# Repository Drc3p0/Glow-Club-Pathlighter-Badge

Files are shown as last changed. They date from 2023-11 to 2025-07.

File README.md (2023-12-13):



<br />
<div align="center">
  <a href="https://github.com/Drc3p0/Glow-Club-Pathlighter-Badge">
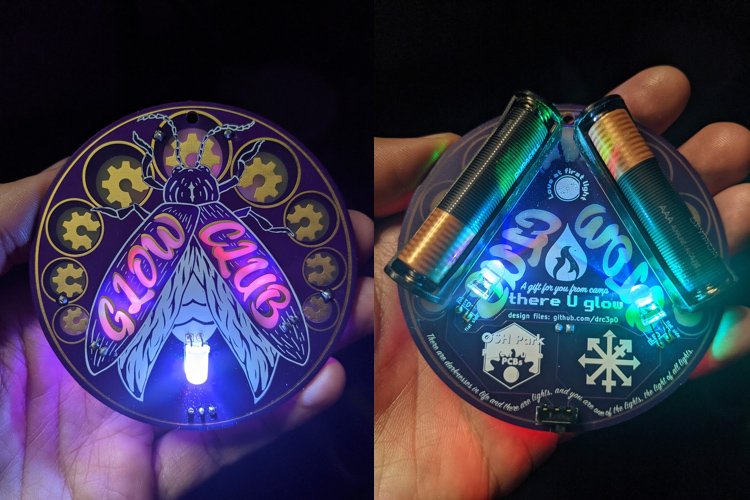
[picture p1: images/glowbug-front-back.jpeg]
glowclub pcb front and back
    
      </a>
 <a href="https://github.com/Drc3p0/Glow-Club-Pathlighter-Badge">
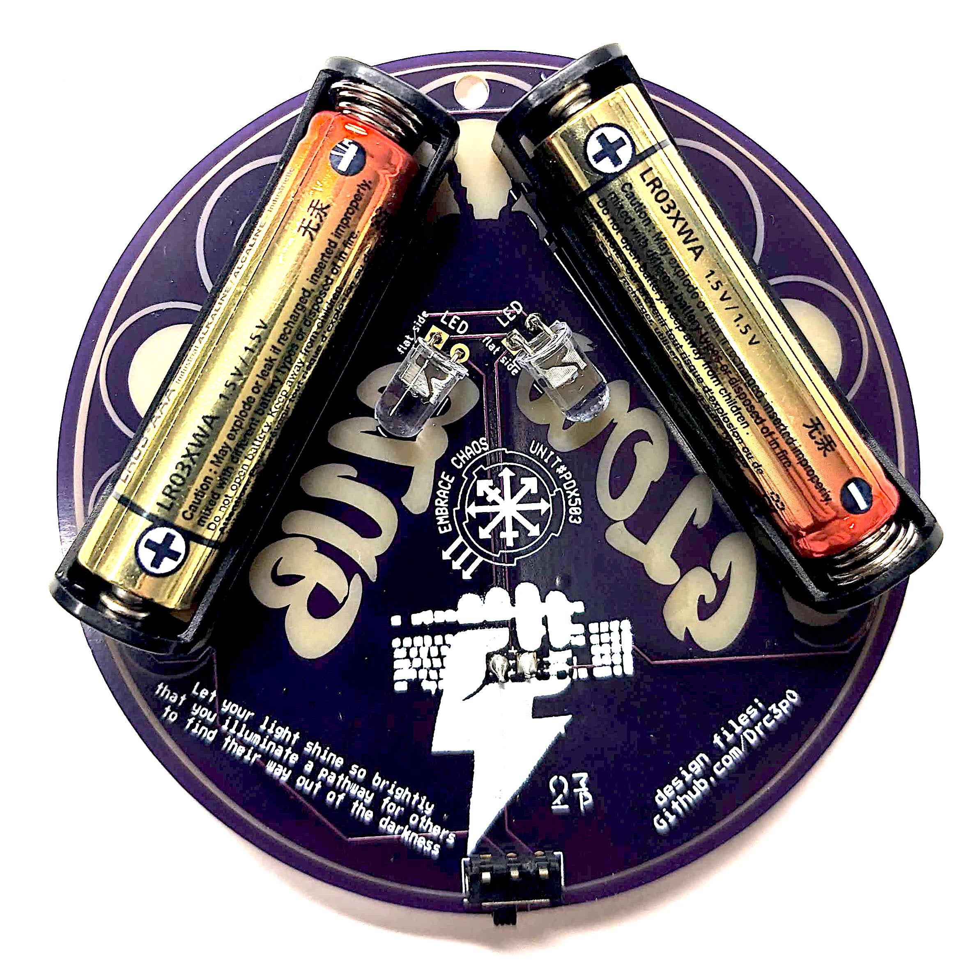
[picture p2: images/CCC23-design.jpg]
    
      </a>

<h3 align="center">Glow Club Pathlighter Badge</h3>

  <p align="center">
    wearable PCB art for the community
  
  </p>
</div>

<!-- ABOUT THE PROJECT -->
## About The Project
This PCB was created as a workshop aid to teach people about LEDs and soldering, and as a way to demistify the process of importing custom art layers into Kicad.  The PCB is intended to be worn on a lanyard, as a way to keep us all glowing safely at night. It was debuted at SOAK '22 for the There U Glow electronics education camp, used for a soldering workshop for ToorCamp 2022 participants, and at Chaos Communication Camp '23. 

signal-2022-07-20-17-38-53-745-3
  
### Created With

* [Procreate](https://procreate.art/)
* [Affinity Designer](https://affinity.serif.com/)
* [Kicad 6.0](https://kicad.org/)
* [OshPark](https://oshpark.com/)

The designs are free to be modified however you'd like.  

<div align="center">
  <a href="https://github.com/Drc3p0/Glow-Club-Pathlighter-Badge">
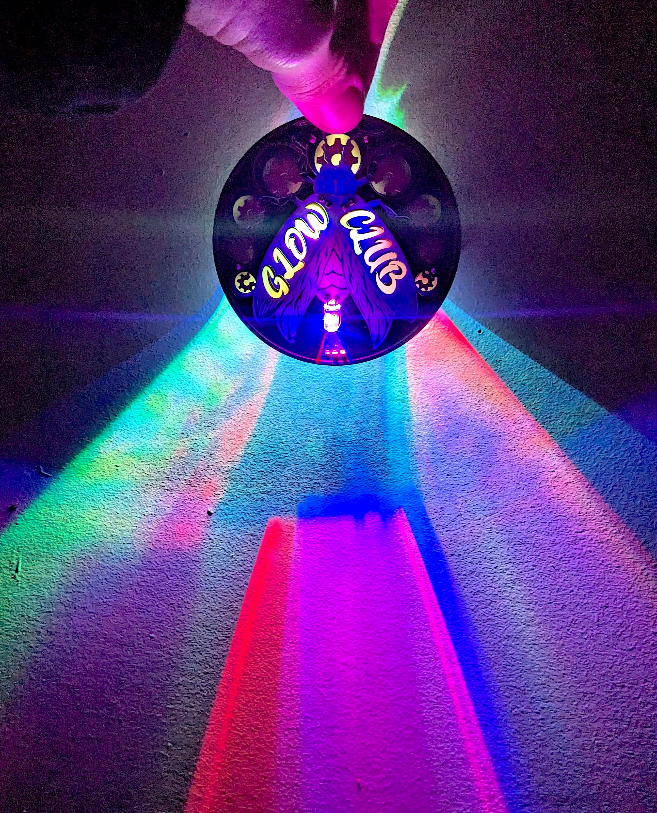
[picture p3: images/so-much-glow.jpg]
much glow!
    
      </a>
</div>

### Build it! 

Components are easy to source and assemble, and consist of a [generic AAA single battery holder x2](https://www.mouser.com/ProductDetail/12BH412-GR), your favorite 5mm LEDs (we like these [color changing ones](https://www.amazon.com/Multicolor-Flashing-Changing-Electronics-Components/dp/B01C19END2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)), and this
[tiny SPDT switch](https://www.mouser.com/ProductDetail/642-MHSS1105) to conserve your battery power.

## Contributing

Contributions are what make the open source community such an amazing place to learn, inspire, and create. Any contributions you make are **greatly appreciated**.

If you have a suggestion that would make this better, please fork the repo and create a pull request. You can also simply open an issue with the tag "enhancement".
Don't forget to give the project a star! Thanks again!

1. Fork the Project
2. Create your Feature Branch (`git checkout -b feature/AmazingFeature`)
3. Commit your Changes (`git commit -m 'Add some AmazingFeature'`)
4. Push to the Branch (`git push origin feature/AmazingFeature`)
5. Open a Pull Request

## License

Distributed under the CERN Open Hardware License (CERN-OHL-W). See `LICENSE.txt` for more information.

## Contact

For inquiries, email me @ [GlowClub@DarcyNeal.com](mailto:glowclub@darcyneal.com)

Project Link: [https://github.com/Drc3p0/Glowbug-Club-PCB](https://github.com/Drc3p0/Glow-Club-Pathlighter-Badge)

<!-- ACKNOWLEDGMENTS -->
## Acknowledgments
Thanks to:
* [OshPark](https://oshpark.org) for providing the PCBs for this community project
* the elusive Josh for providing power consumption data
* there U glow camp @ [SOAK](https://soakpdx.com/) for helping distribute these boards & [teach folks about LEDs](https://docs.google.com/document/d/180WD4LogMjx8FmKcFc0dmlTEKJ1Xa7dIHlEhSLMOAxA/edit?usp=sharing)
* [Toorcamp 2022](https://talks.toorcon.net/toorcamp-2020-2019/talk/DNWBQS/).  Over 75 students were able to assemble badges during the ~2 hr workshop.
* [Chaos Communication Camp '23 and the Hardware Hacking Village](https://events.ccc.de/camp/2023/hub/camp23/en/event/solder-a-pathlighter-pcb-badge-day-1/).  Over 160 students completed their badges over two workshops, each ~1.5hrs. 
<p align="right">(<a href="#top">back to top</a>)</p>

To date, the Glow Club now has over 450 members! May we all shine a little brighter as a result. :)

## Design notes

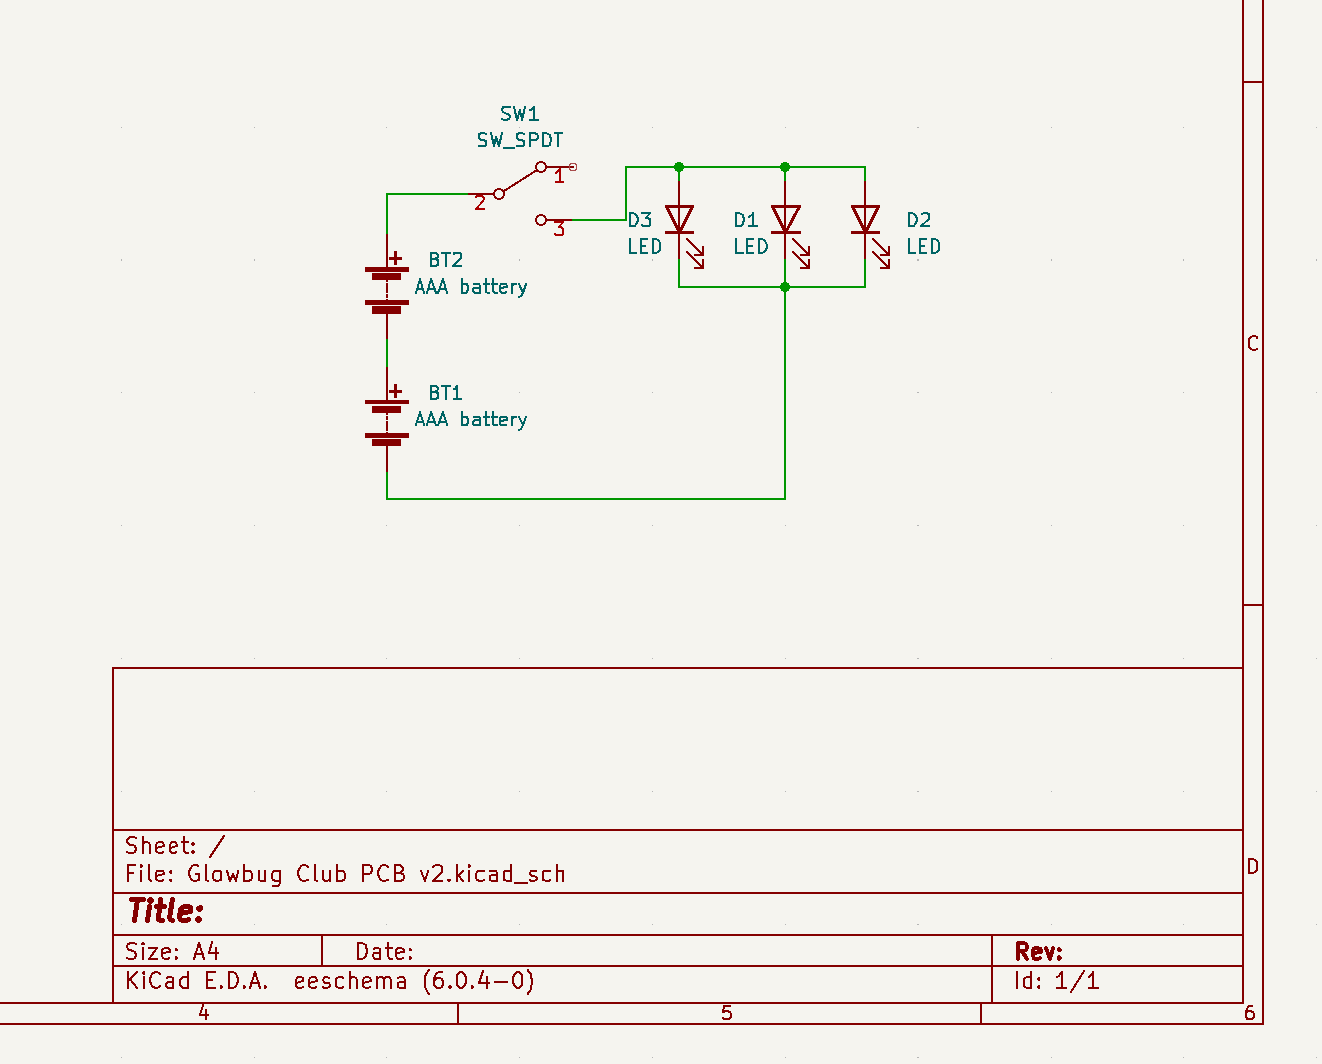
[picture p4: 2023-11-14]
images/Glowbug Club Schematic.png

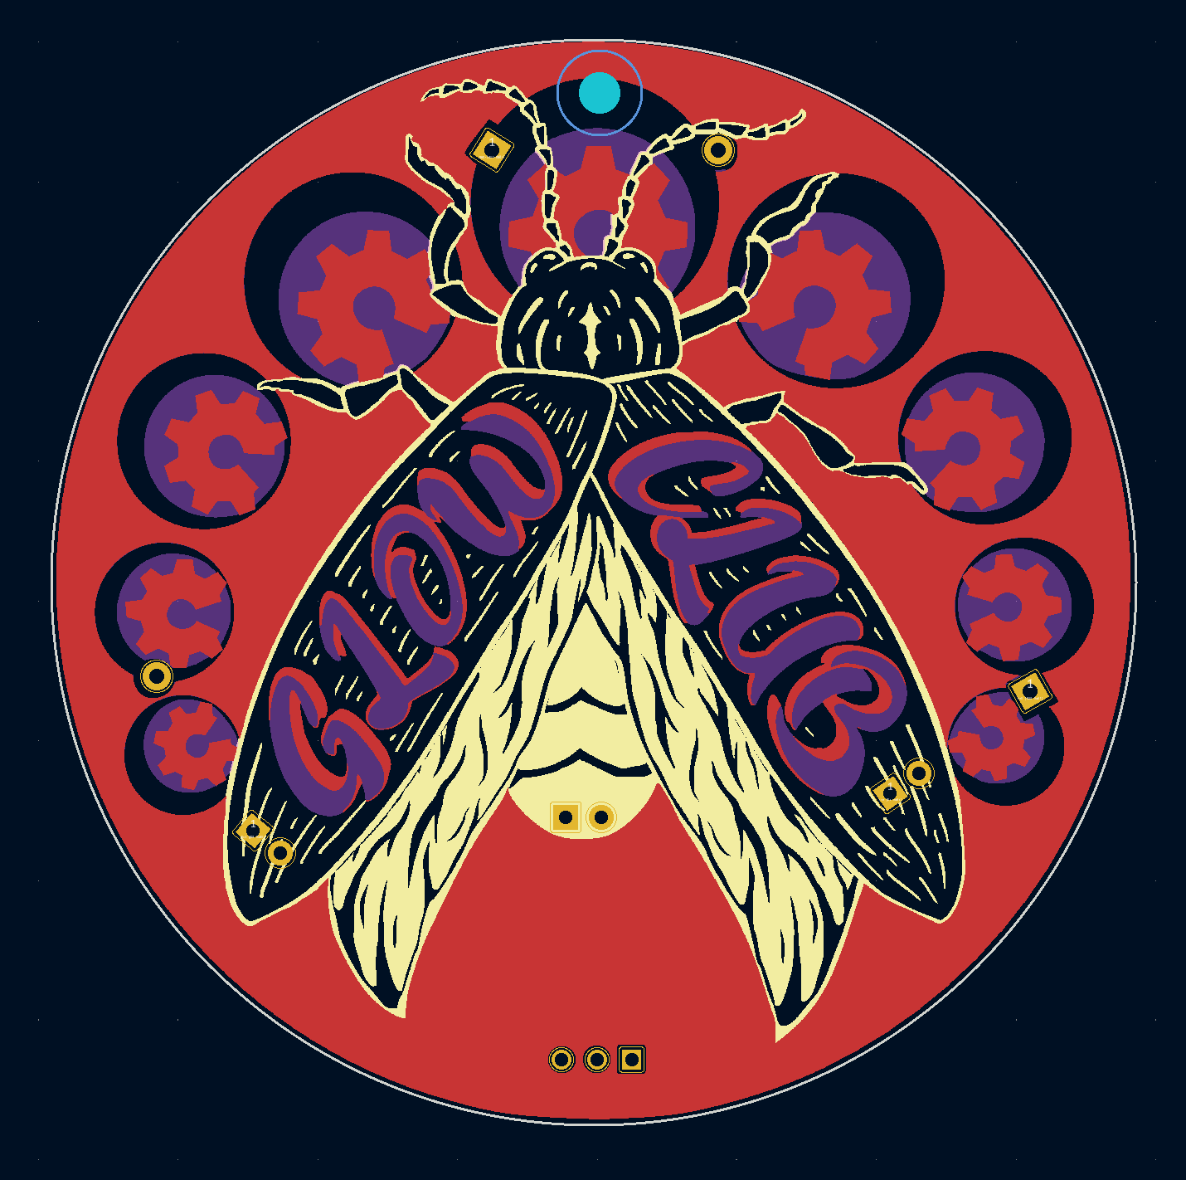
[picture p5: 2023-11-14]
images/screenshots/Kicad Screen Shot Copper Layer.png

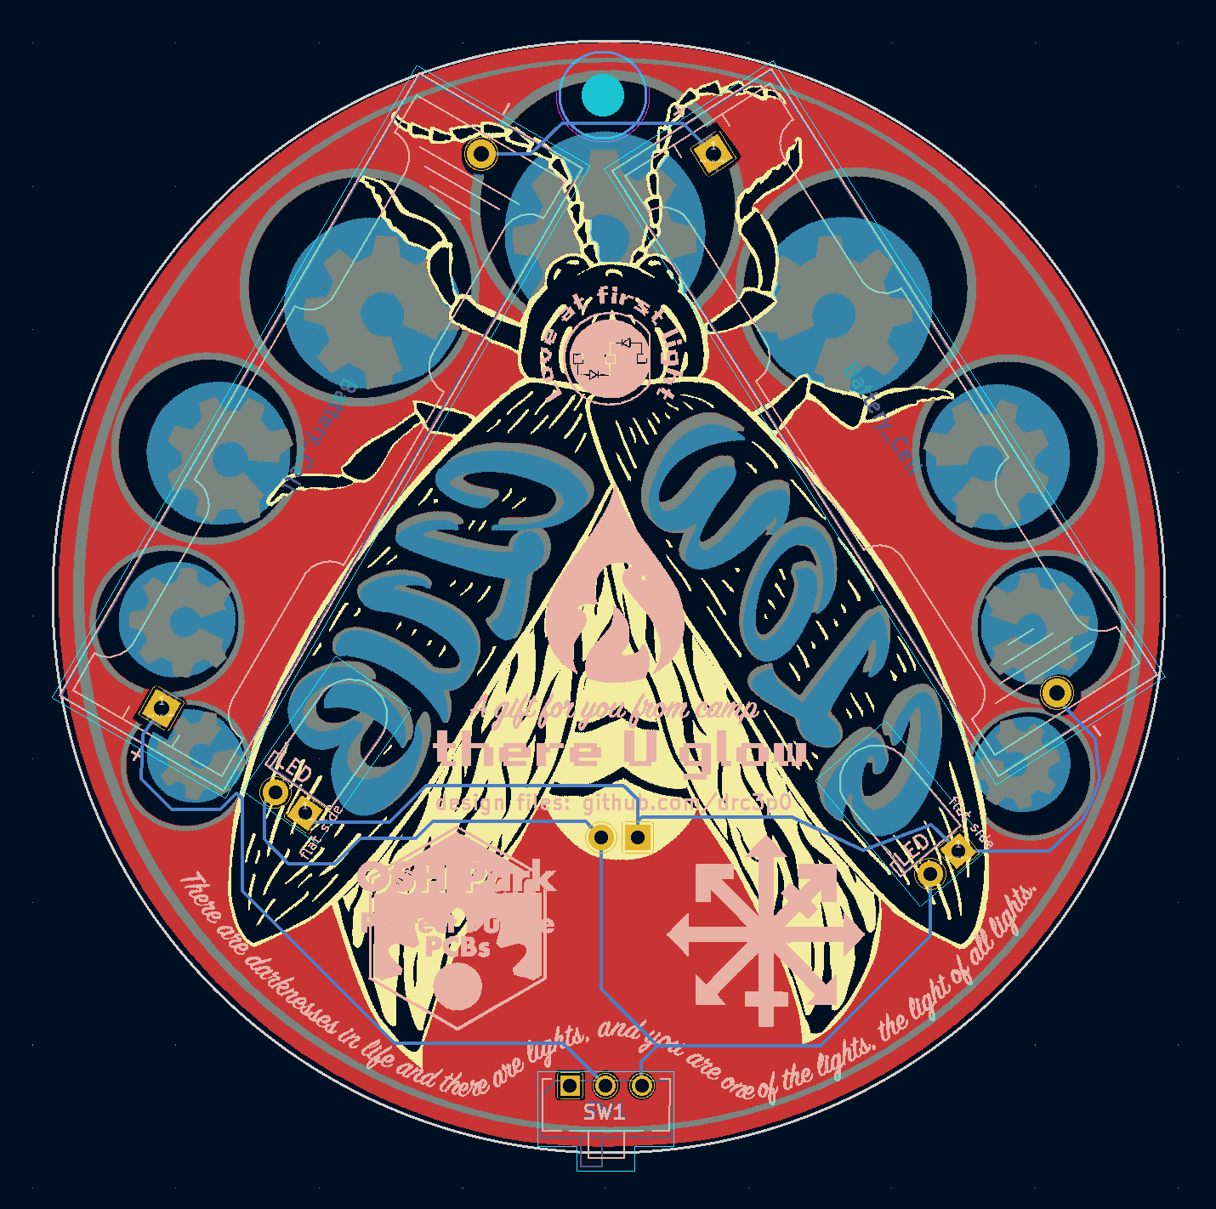
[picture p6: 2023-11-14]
images/screenshots/Kicad Screen Shot All Layers.png

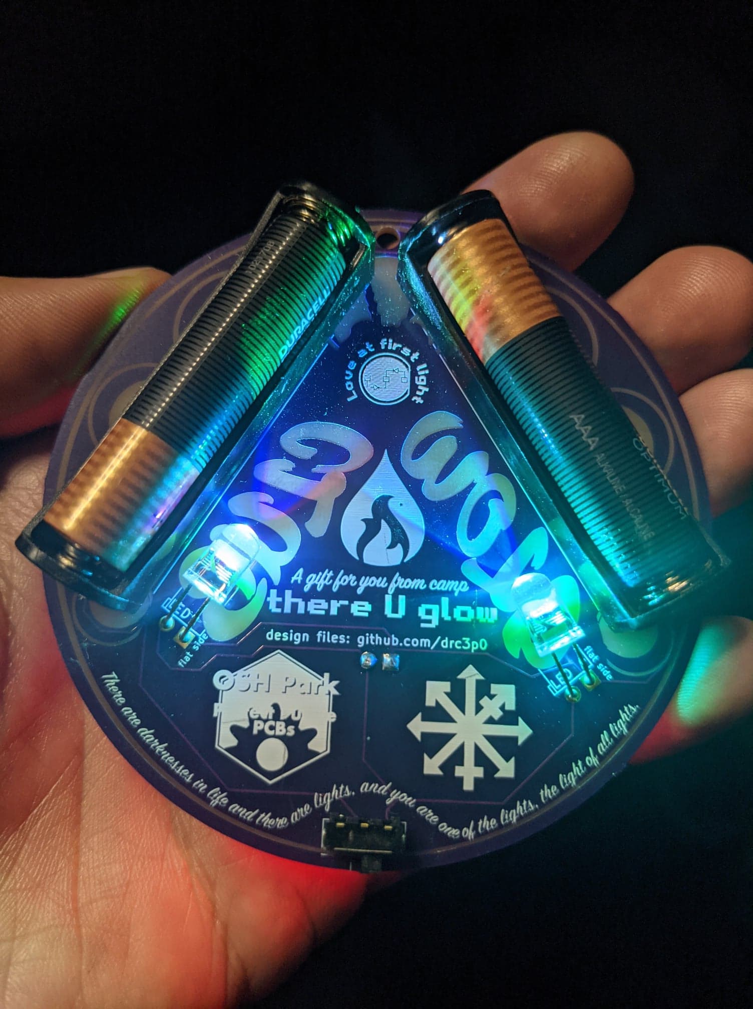
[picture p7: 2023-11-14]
images/Glowbug PCB back.jpeg

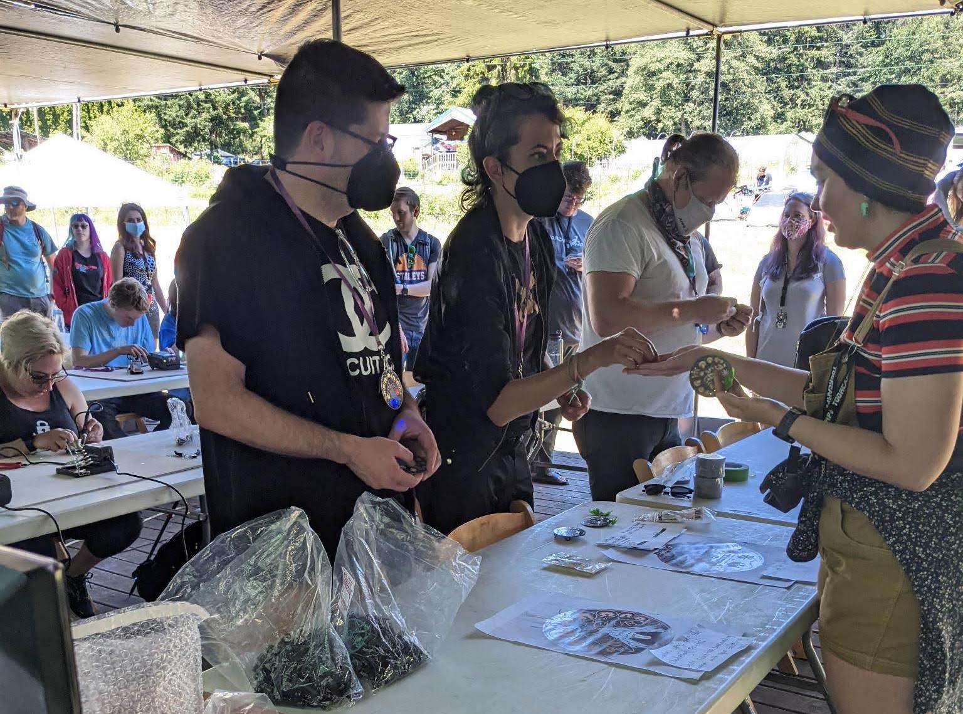
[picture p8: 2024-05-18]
images/toorcamp22-workshop.jpg

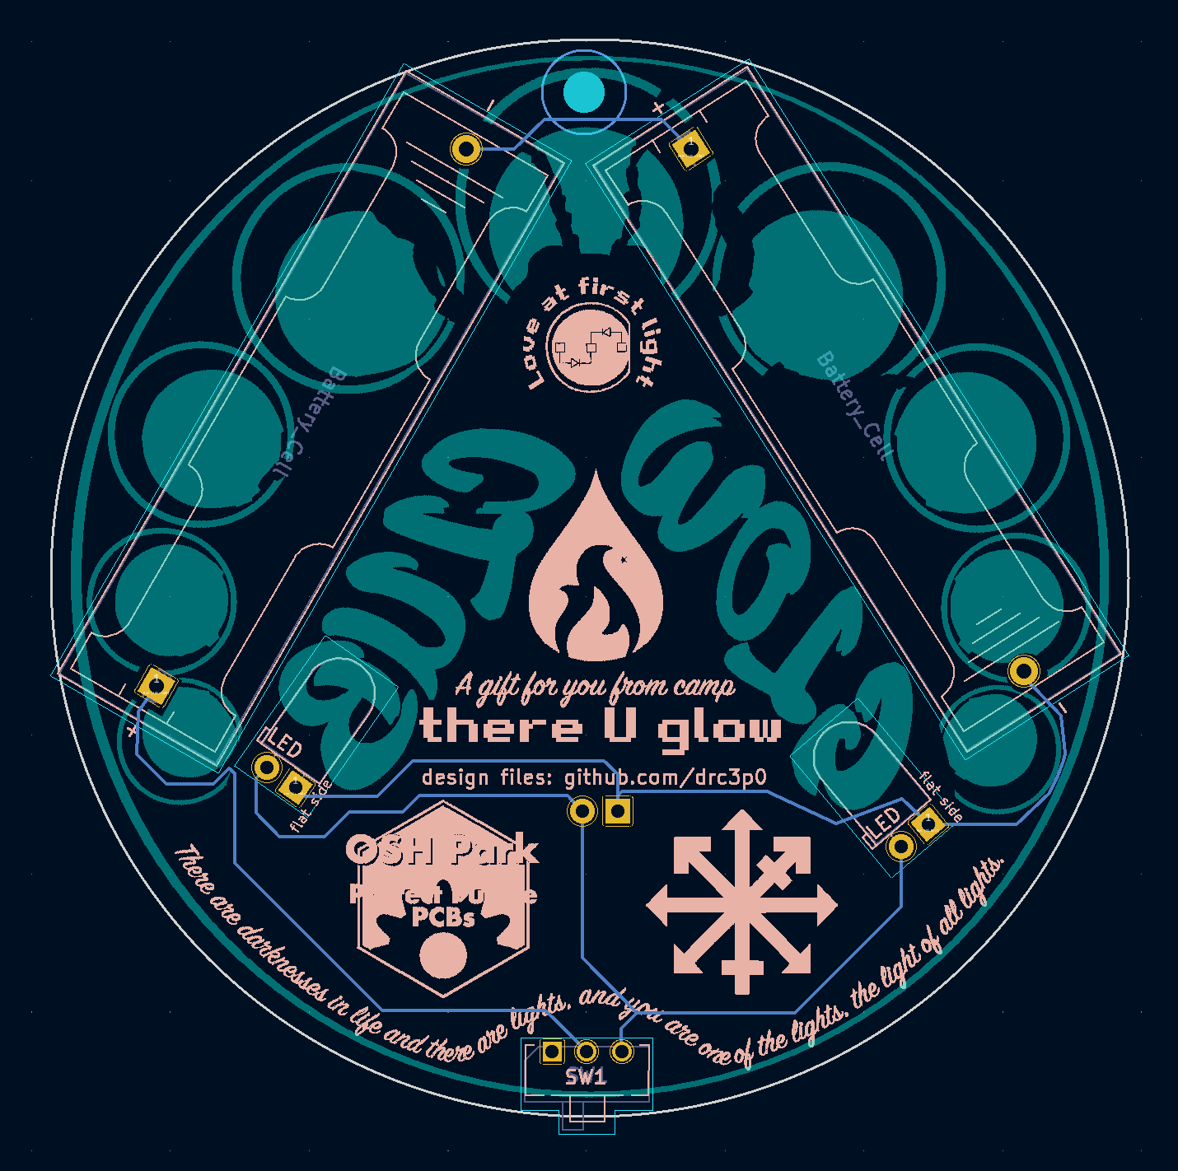
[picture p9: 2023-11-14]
images/screenshots/Kicad Screen Shot Mask Layer.png

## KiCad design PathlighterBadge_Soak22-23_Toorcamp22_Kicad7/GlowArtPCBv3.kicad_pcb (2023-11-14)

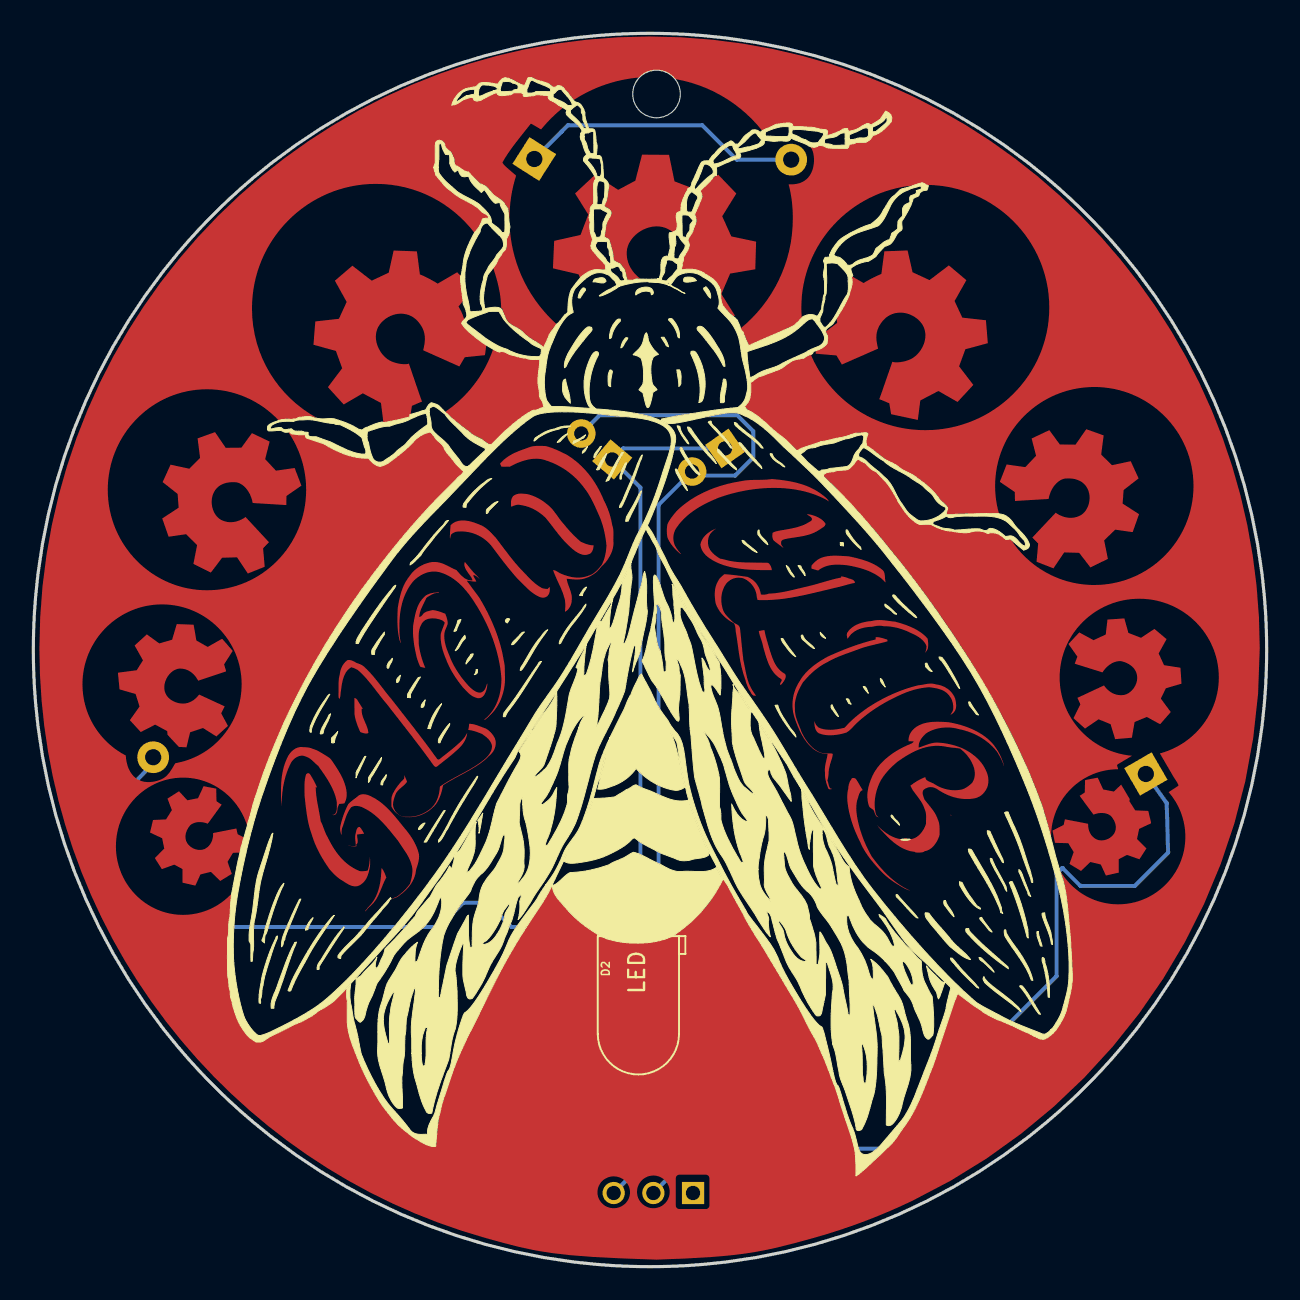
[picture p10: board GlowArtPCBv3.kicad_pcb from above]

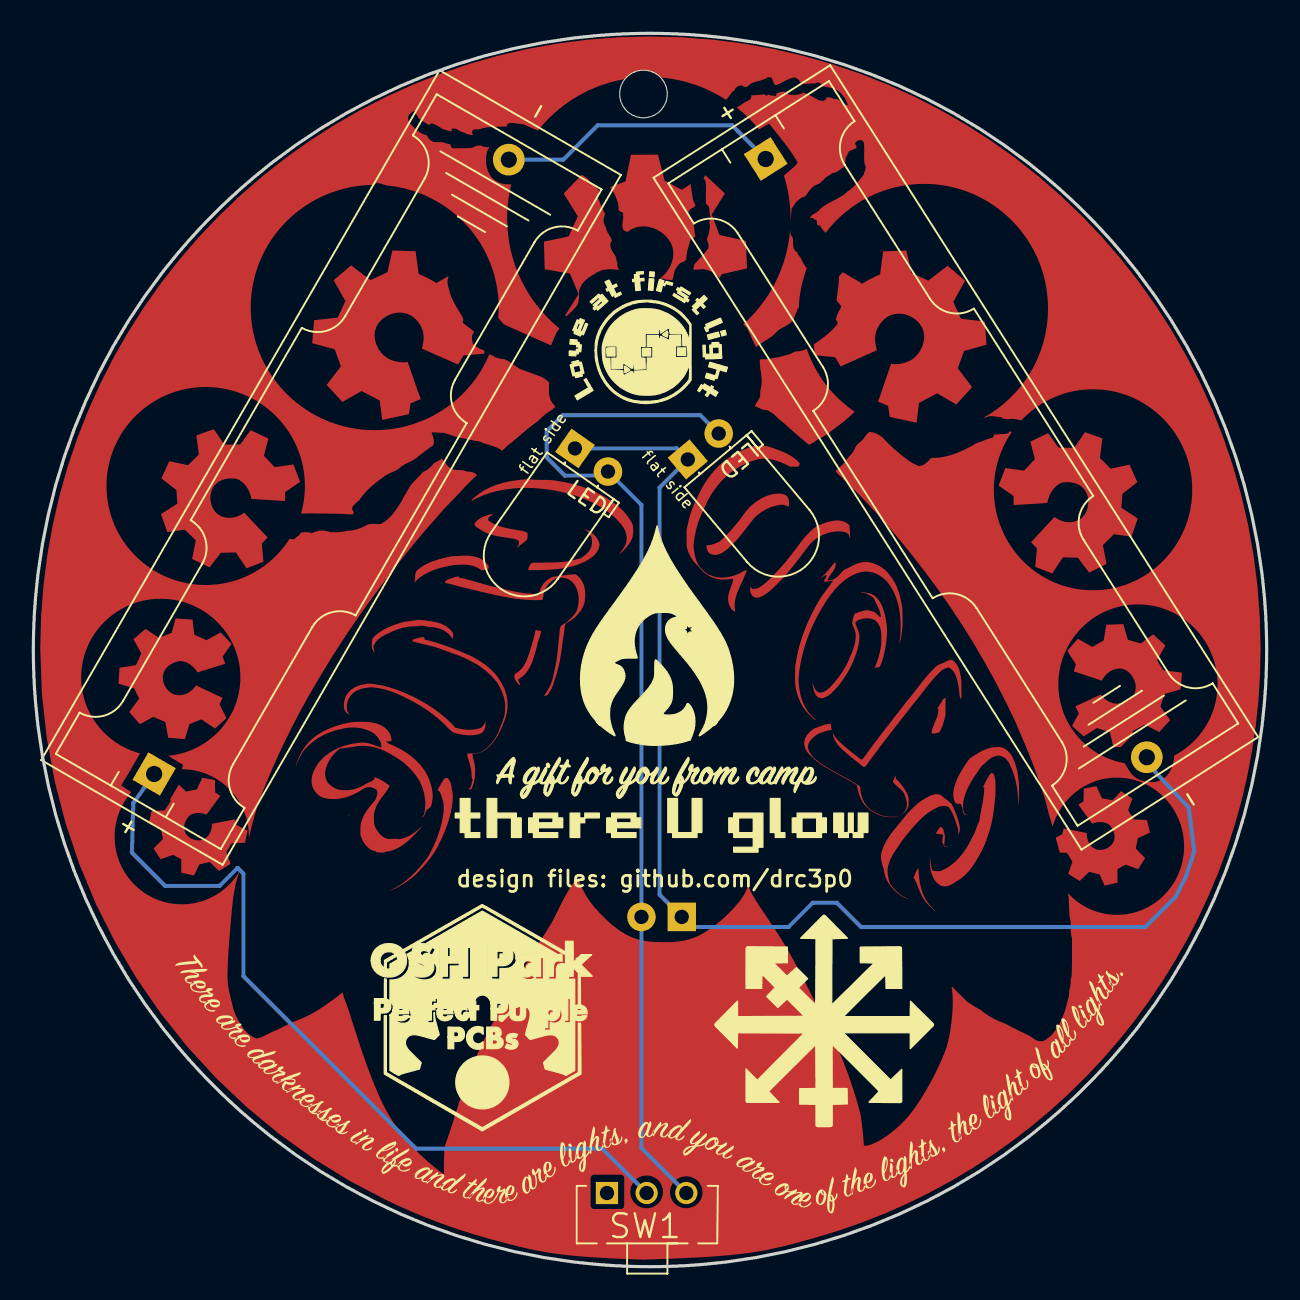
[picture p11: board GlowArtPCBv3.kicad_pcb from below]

Board: 2 copper layers, 77.7 x 77.7 mm, 6 parts (5 on the bottom side), 4 nets.

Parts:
BT1, BT2: AAA battery; BatteryHolder_Keystone_2466_1xAAA
D2: LED; LED_D5.0mm_Horizontal_O1.27mm_Z3.0mm
SW1: SW_SPDT; SW_MHSS1105_SPST_Angled
flat side: LED; LED_D5.0mm_Horizontal_O1.27mm_Z3.0mm
flat side#2: LED; LED_D5.0mm_Horizontal_O1.27mm_Z3.0mm

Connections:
unnamed: BT1.1 (+), BT2.2 (-)
unnamed: BT1.2 (-), D2.1 (K), flat side.1 (K), flat side#2.1 (K)
unnamed: BT2.1 (+), SW1.2 (B)
unnamed: D2.2 (A), SW1.3 (C), flat side.2 (A), flat side#2.2 (A)

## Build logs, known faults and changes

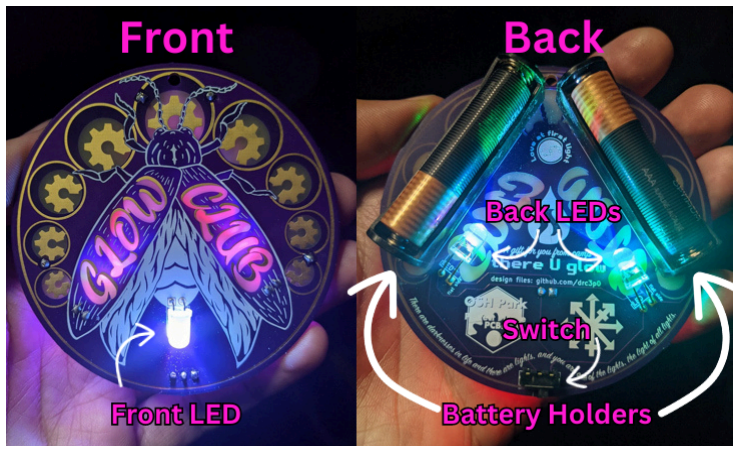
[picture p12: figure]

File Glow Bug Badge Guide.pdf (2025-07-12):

## There U Glow’s Glow Bug Badge Quickstart Guide!

This Art PCB was created by Darcy Neal as a fully open source workshop aid and gift to teach people about LEDs and soldering, as well as teach PCB (KiCad) design and manufacturing basics.

Step 1. Gather all the bits you need (from a workshop lead):
- ONE round Glow Bug PCB
- ONE small switch
- ONE purple lanyard
- TWO AAA single battery holders
- TWO AAA batteries
- THREE color changing LEDs, two bent long, one bent short

Common Mistakes: Know which side is the front, and which is the back. Try not to bridge any pins or copper traces to other pins, with solder, particularly with the small switch. Place your battery holders in the correct direction. Ask for help if needed!

Step 2. Solder! In no particular order you will solder:
- The switch onto the bottom of the badge. It has three small legs that poke through the PCB. Don’t bridge them! (meaning, don’t get solder stuck between them, making them touch)
- The battery holders onto the back, make sure they are placed IN THE CORRECT DIRECTION. Positive and negative are marked on the board, and on the battery holders.
- The two long-bent LEDs onto the back, through the holes. They should point down, towards the switch. (The badge in the photo below is slightly outdated, so pay attention to your badge and point them down!)
- Finally, flip the badge over and solder the single short-bent LED onto the front, pointing down towards the switch, as the glowing butt of the glow bug.
- Test your badge with the batteries, add a lanyard. Troubleshoot if needed. It’s ok if it doesn’t work at first! We can fix any mistakes, and we are here to help you.
